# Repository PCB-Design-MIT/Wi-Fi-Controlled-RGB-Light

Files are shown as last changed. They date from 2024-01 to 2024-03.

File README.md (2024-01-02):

# Wi-Fi-Controlled-RGB-Light

A demo board for students to learn to solder and debug

Designed by: [Deepta Gupta](https://github.com/deeptag0307), [Winnie Szeto](https://github.com/wszeto9) for IAP 2024

[Interactive BOM](https://htmlpreview.github.io/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)

[Interactive Schematic and Layout Viewer](https://kicanvas.org/?github=https%3A%2F%2Fgithub.com%2FPCB-Design-MIT%2FWi-Fi-Controlled-RGB-Light)

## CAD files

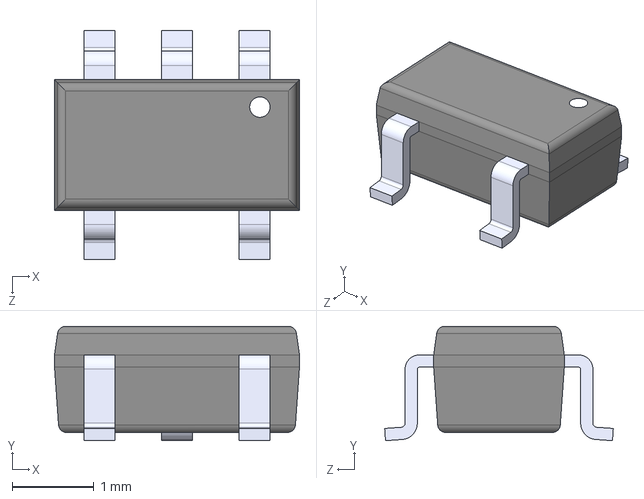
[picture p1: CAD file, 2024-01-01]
parts/AP2112K-3.3TRG1/AP2112K-3.3TRG1.step
3.00 x 1.40 x 2.80 mm

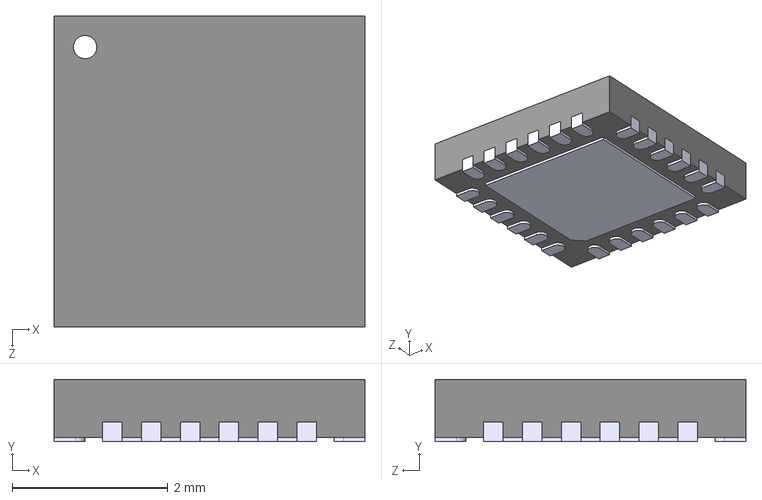
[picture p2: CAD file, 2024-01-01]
parts/CP2104-F03-GM/CP2104-F03-GM.step
4.00 x 0.8 x 4.00 mm

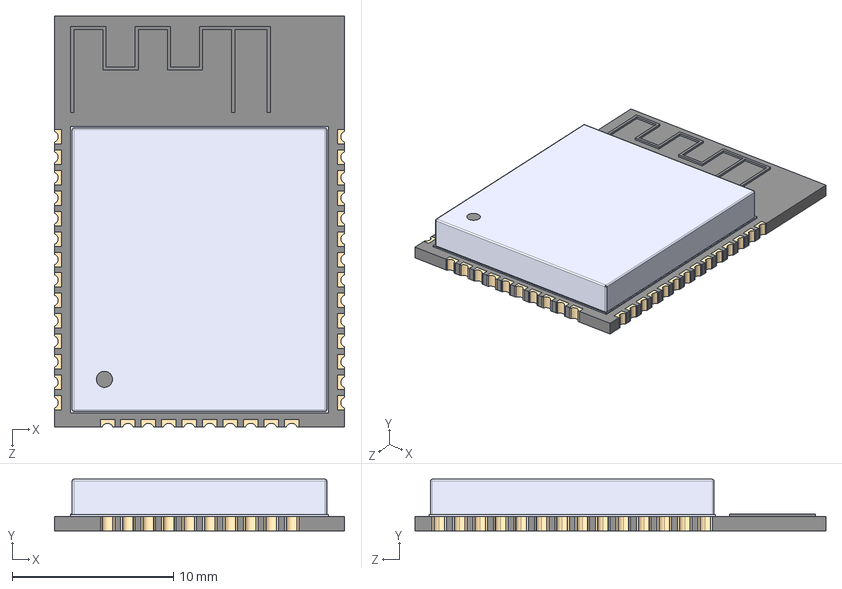
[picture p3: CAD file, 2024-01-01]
parts/ESP32-WROOM-32/ESP32-WROOM-32.step
18.0 x 3.20 x 25.5 mm

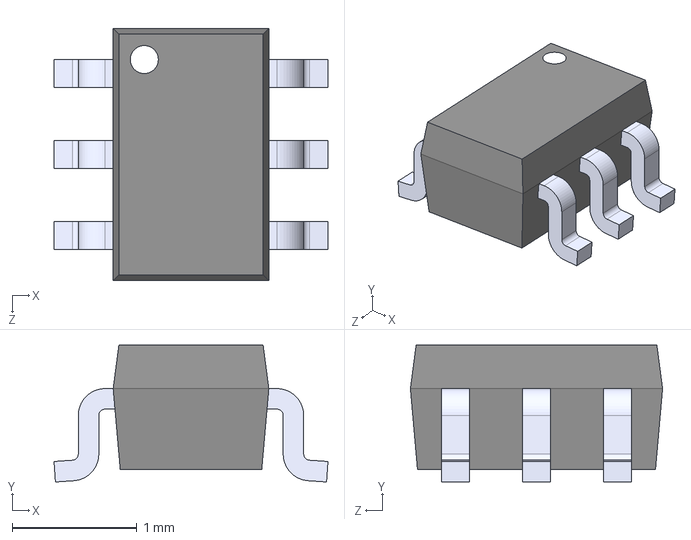
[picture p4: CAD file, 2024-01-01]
parts/MBT3904DW1T1G/MBT3904DW1T1G.step
2.20 x 1.10 x 2.03 mm

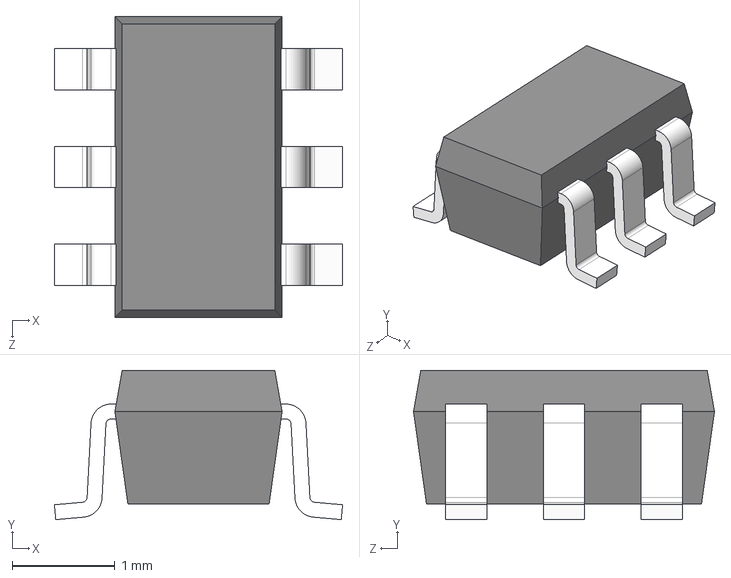
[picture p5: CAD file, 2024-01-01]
parts/TPS61170DRVR/USBLC6-2SC6/USBLC6-2SC6.step
2.80 x 1.45 x 2.92 mm

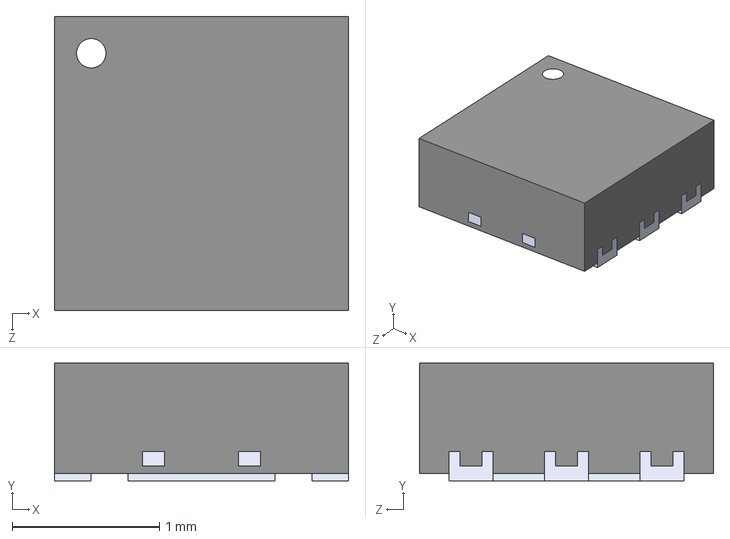
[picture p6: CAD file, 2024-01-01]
parts/TPS61170DRVR/TPS61170DRVR.step
2.00 x 0.8 x 2.00 mm

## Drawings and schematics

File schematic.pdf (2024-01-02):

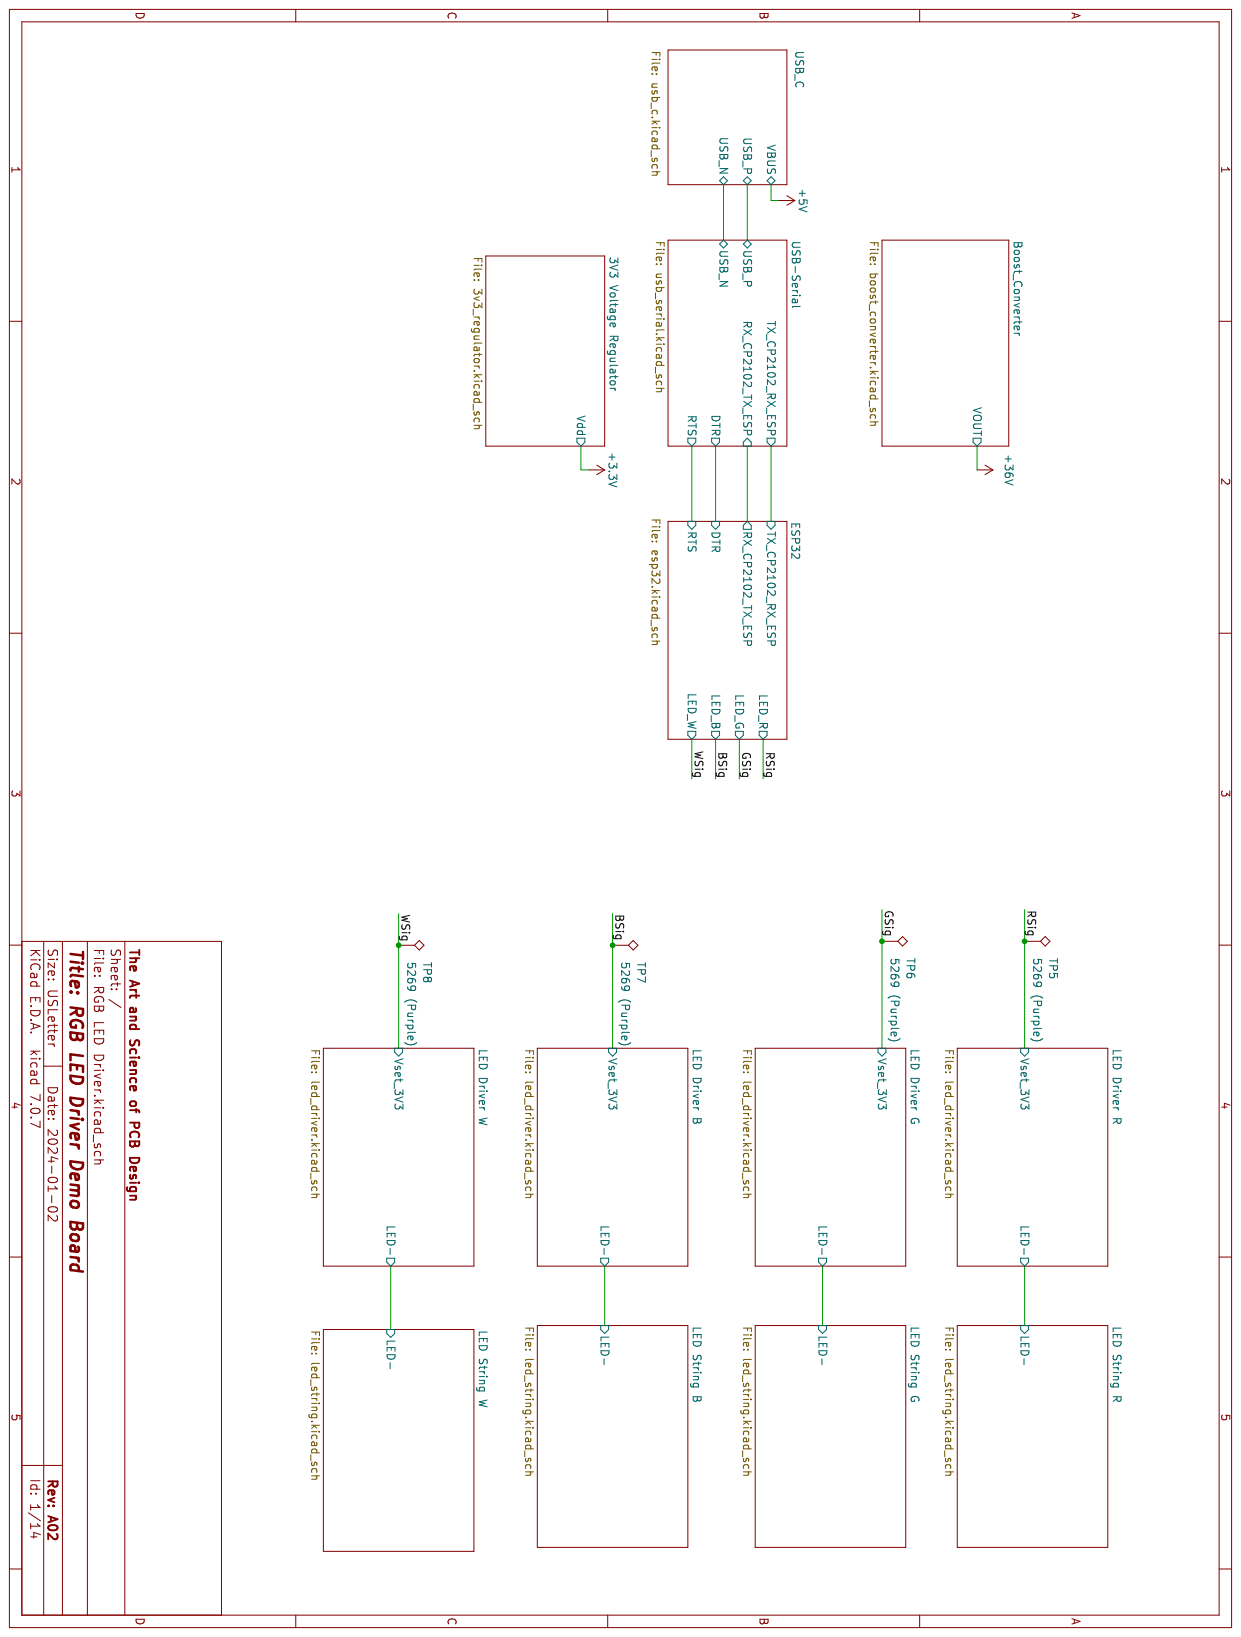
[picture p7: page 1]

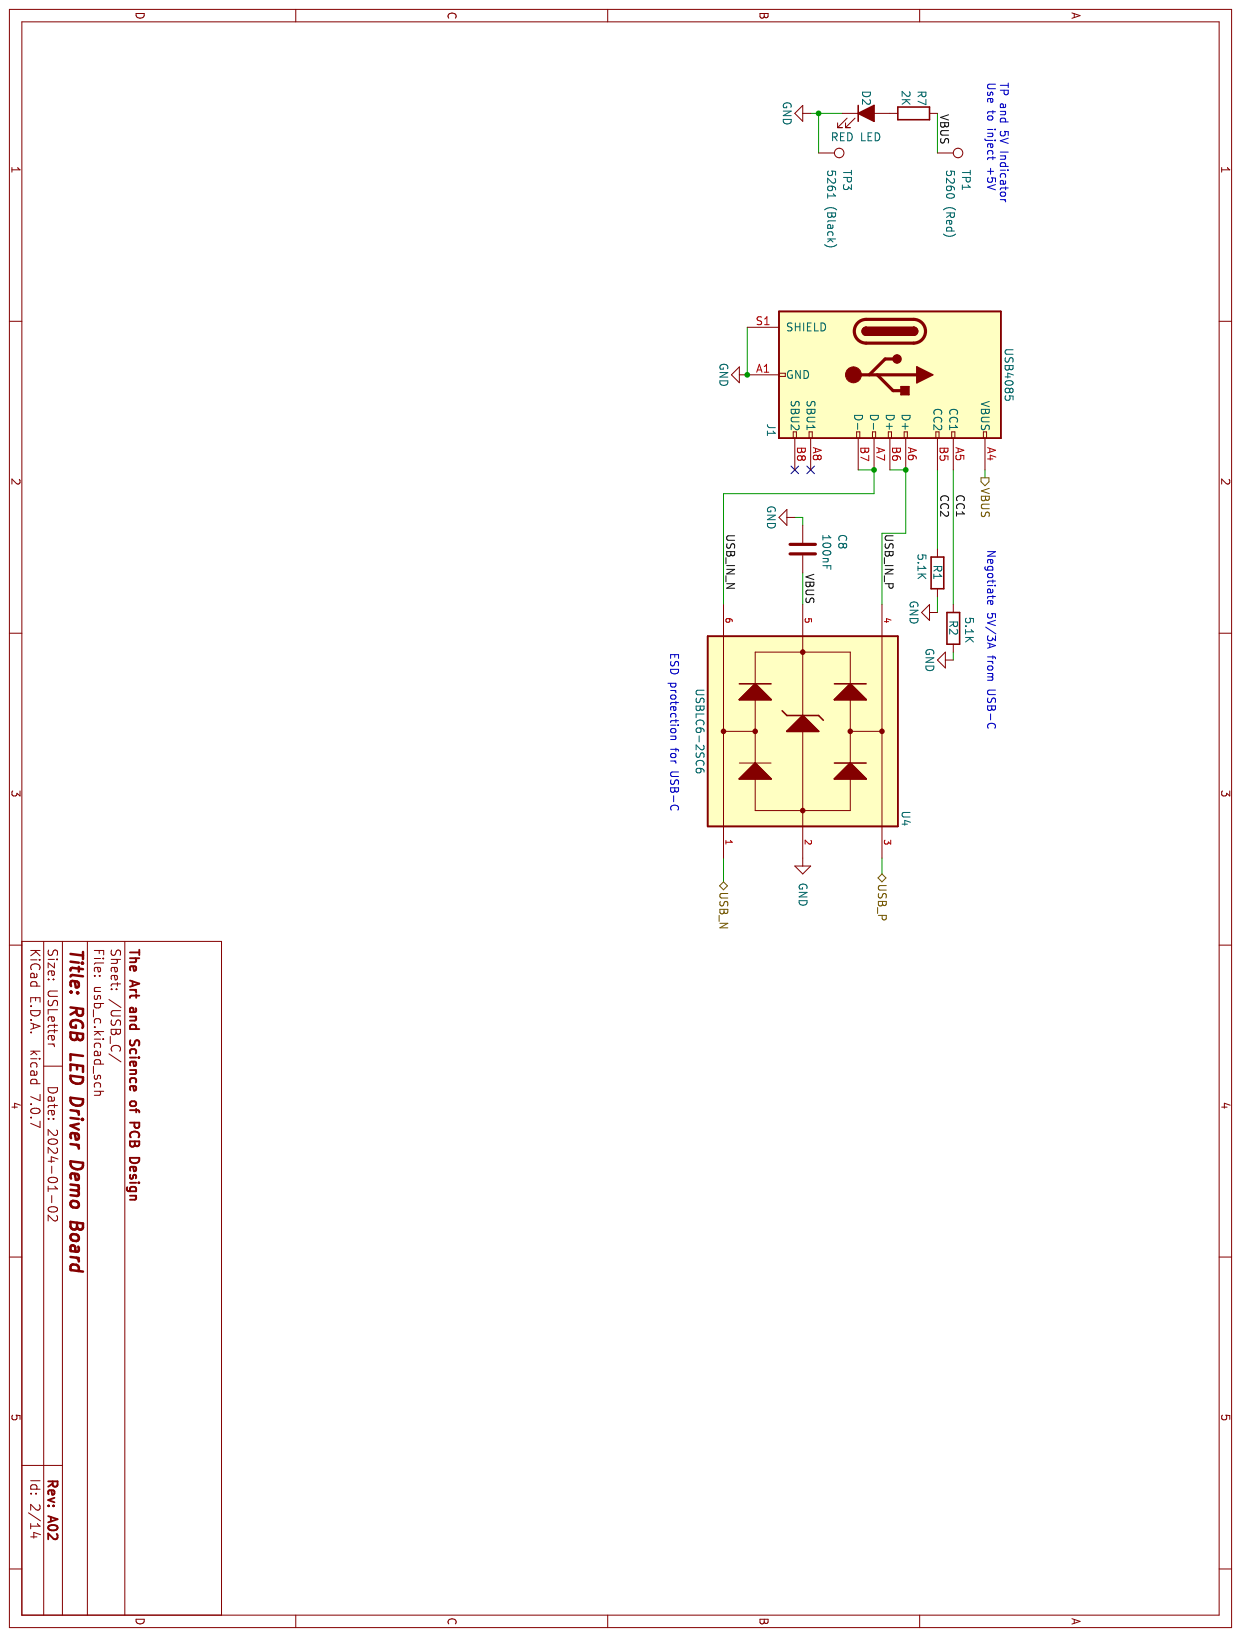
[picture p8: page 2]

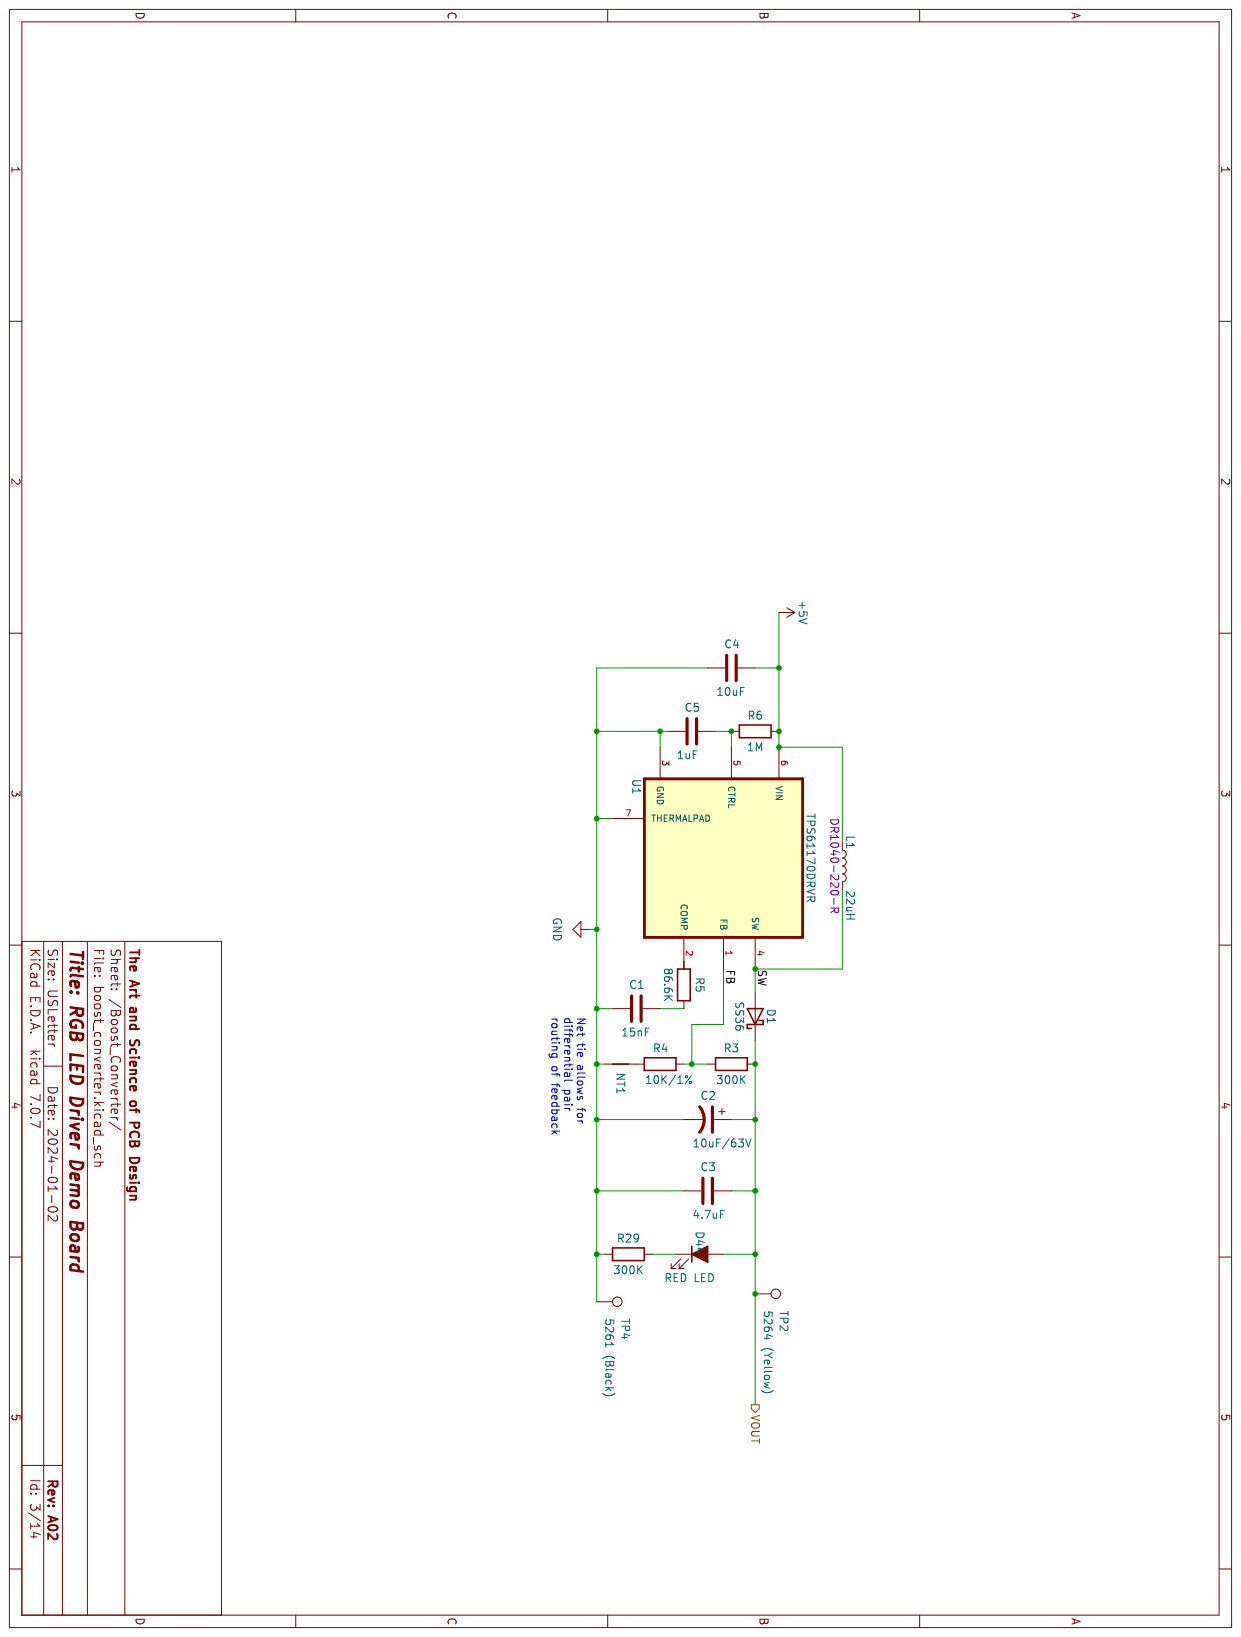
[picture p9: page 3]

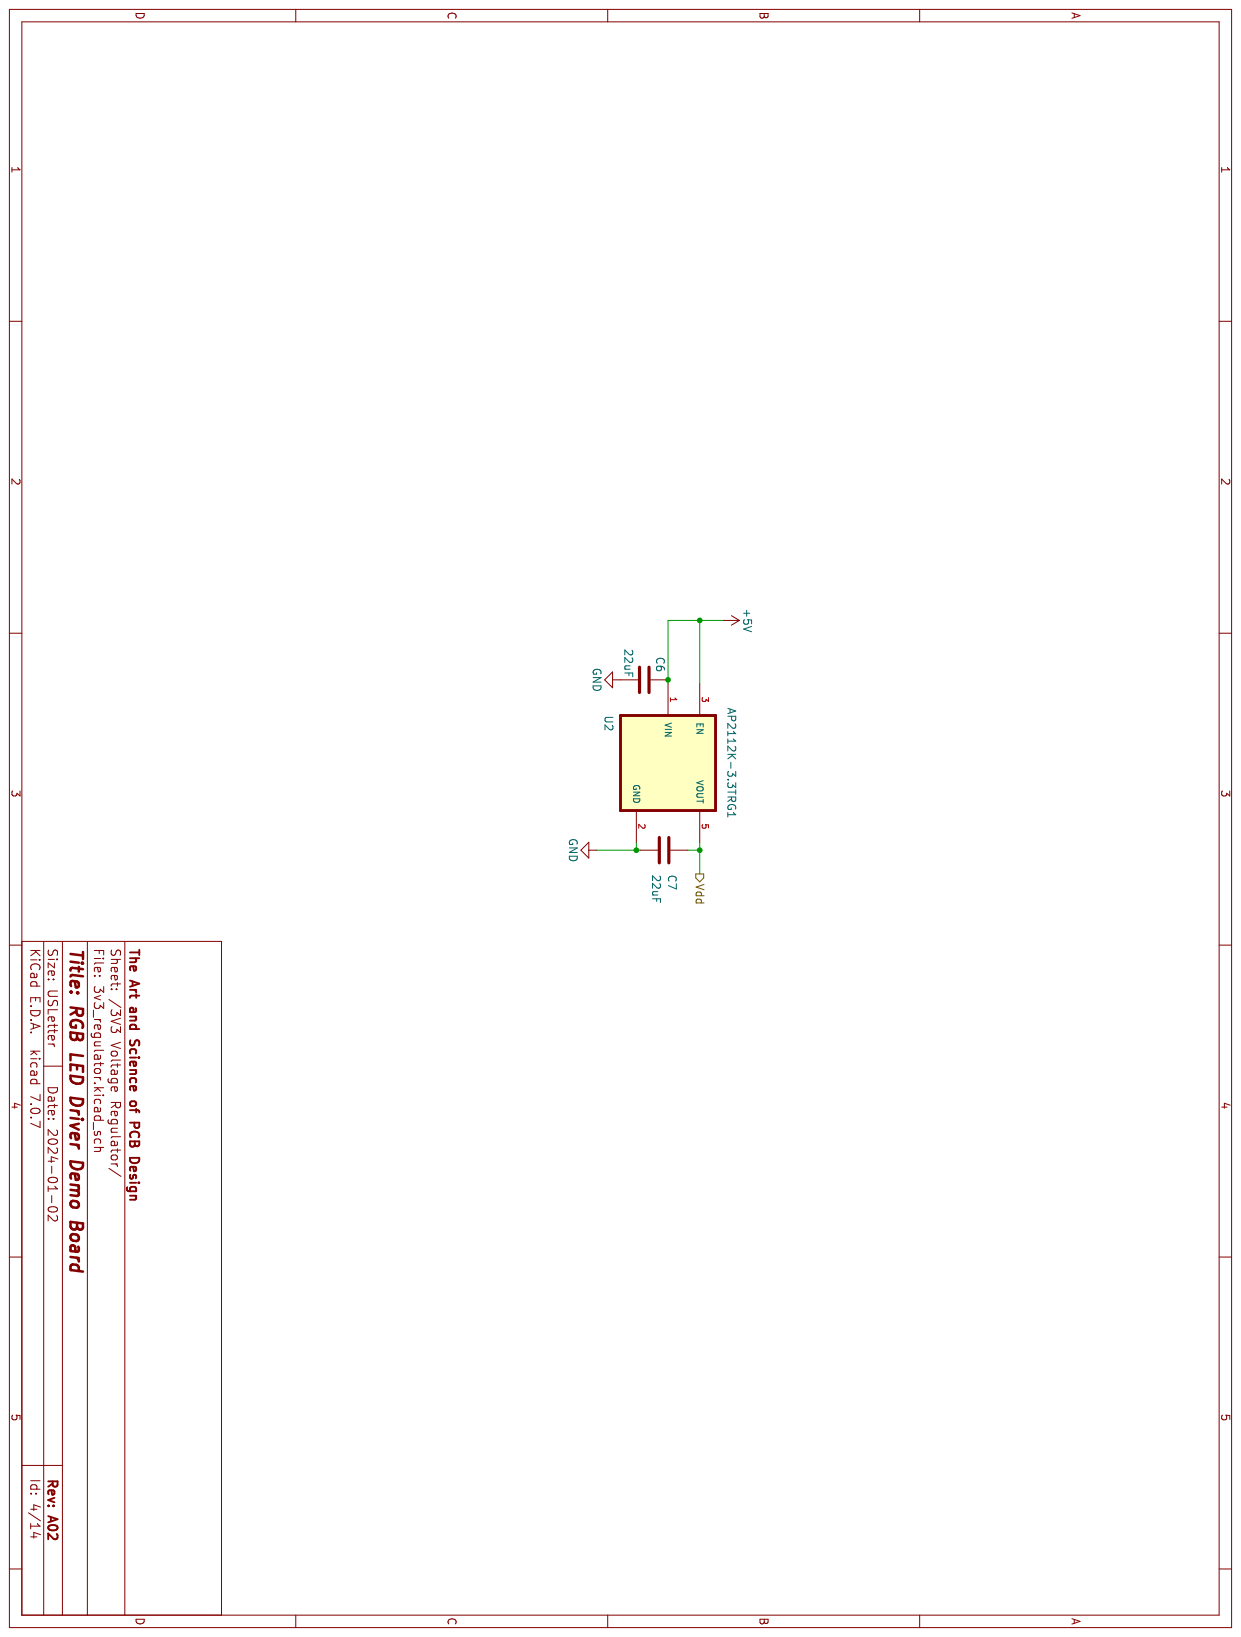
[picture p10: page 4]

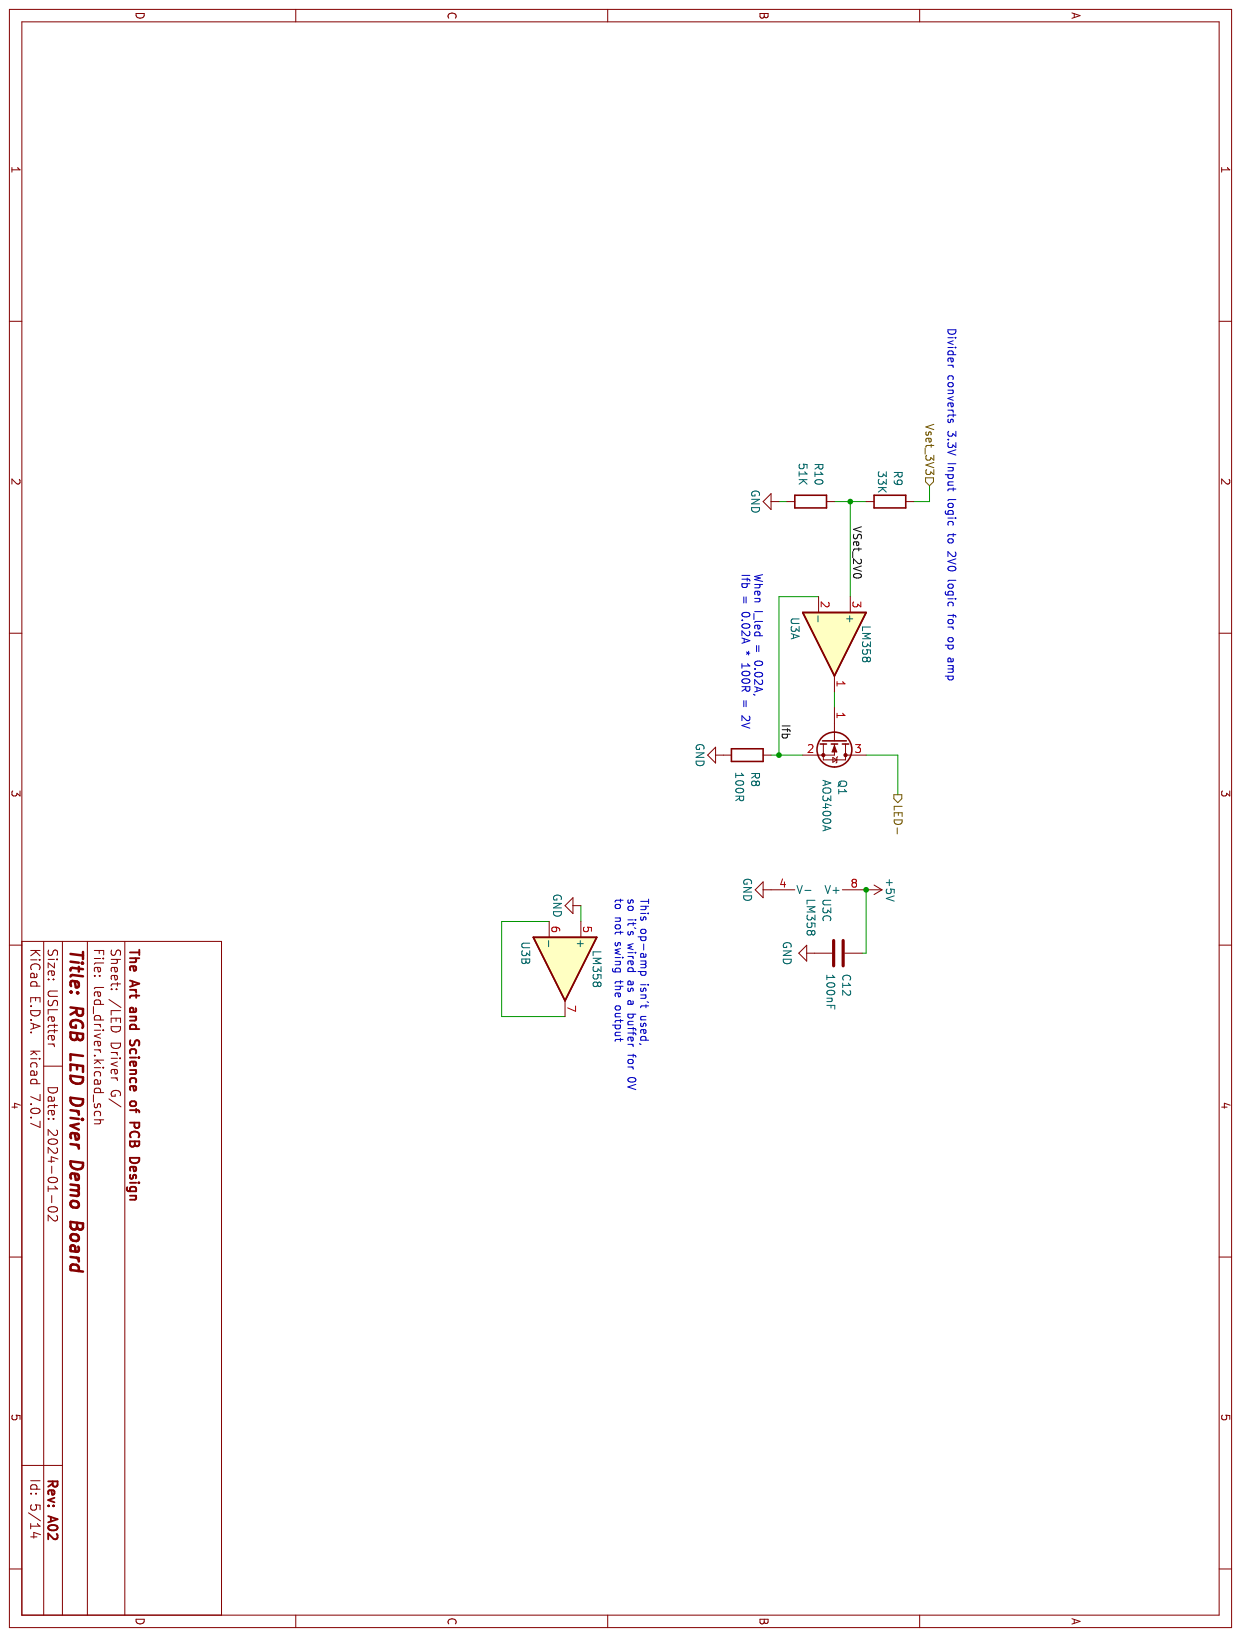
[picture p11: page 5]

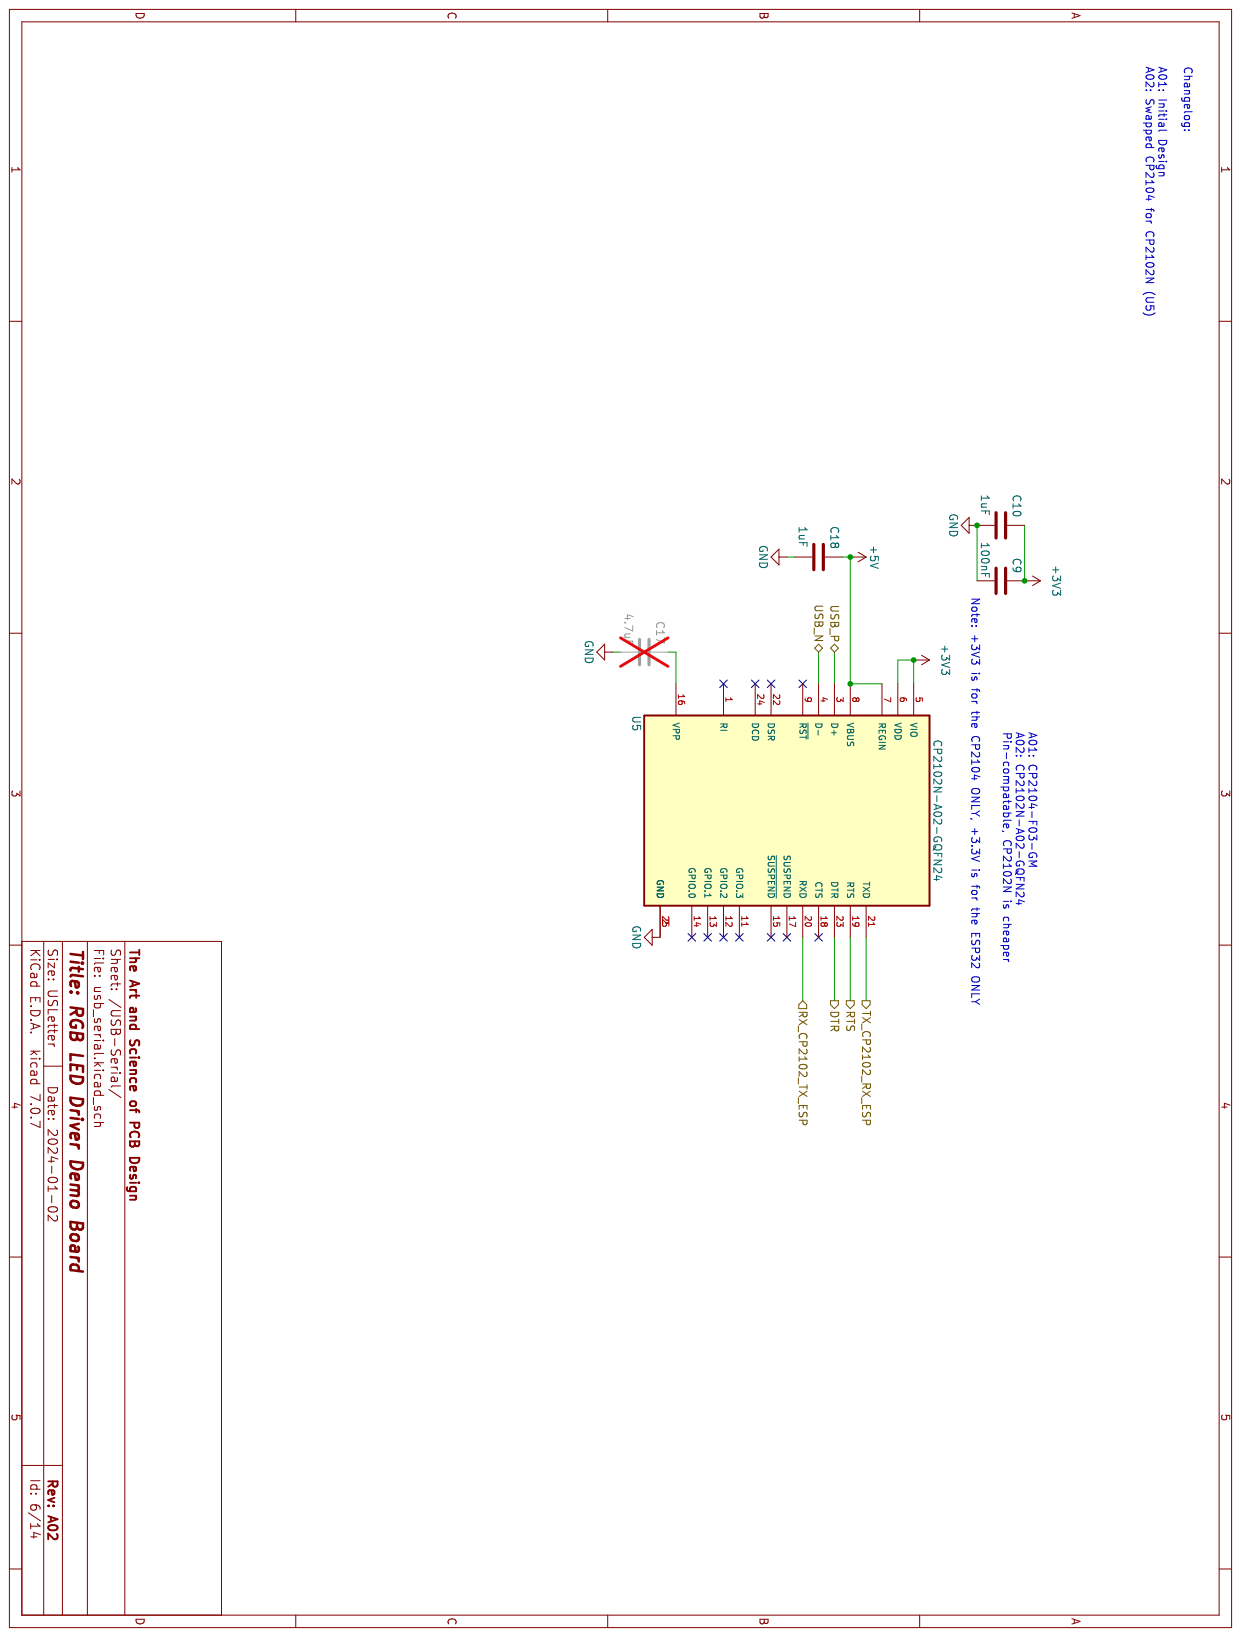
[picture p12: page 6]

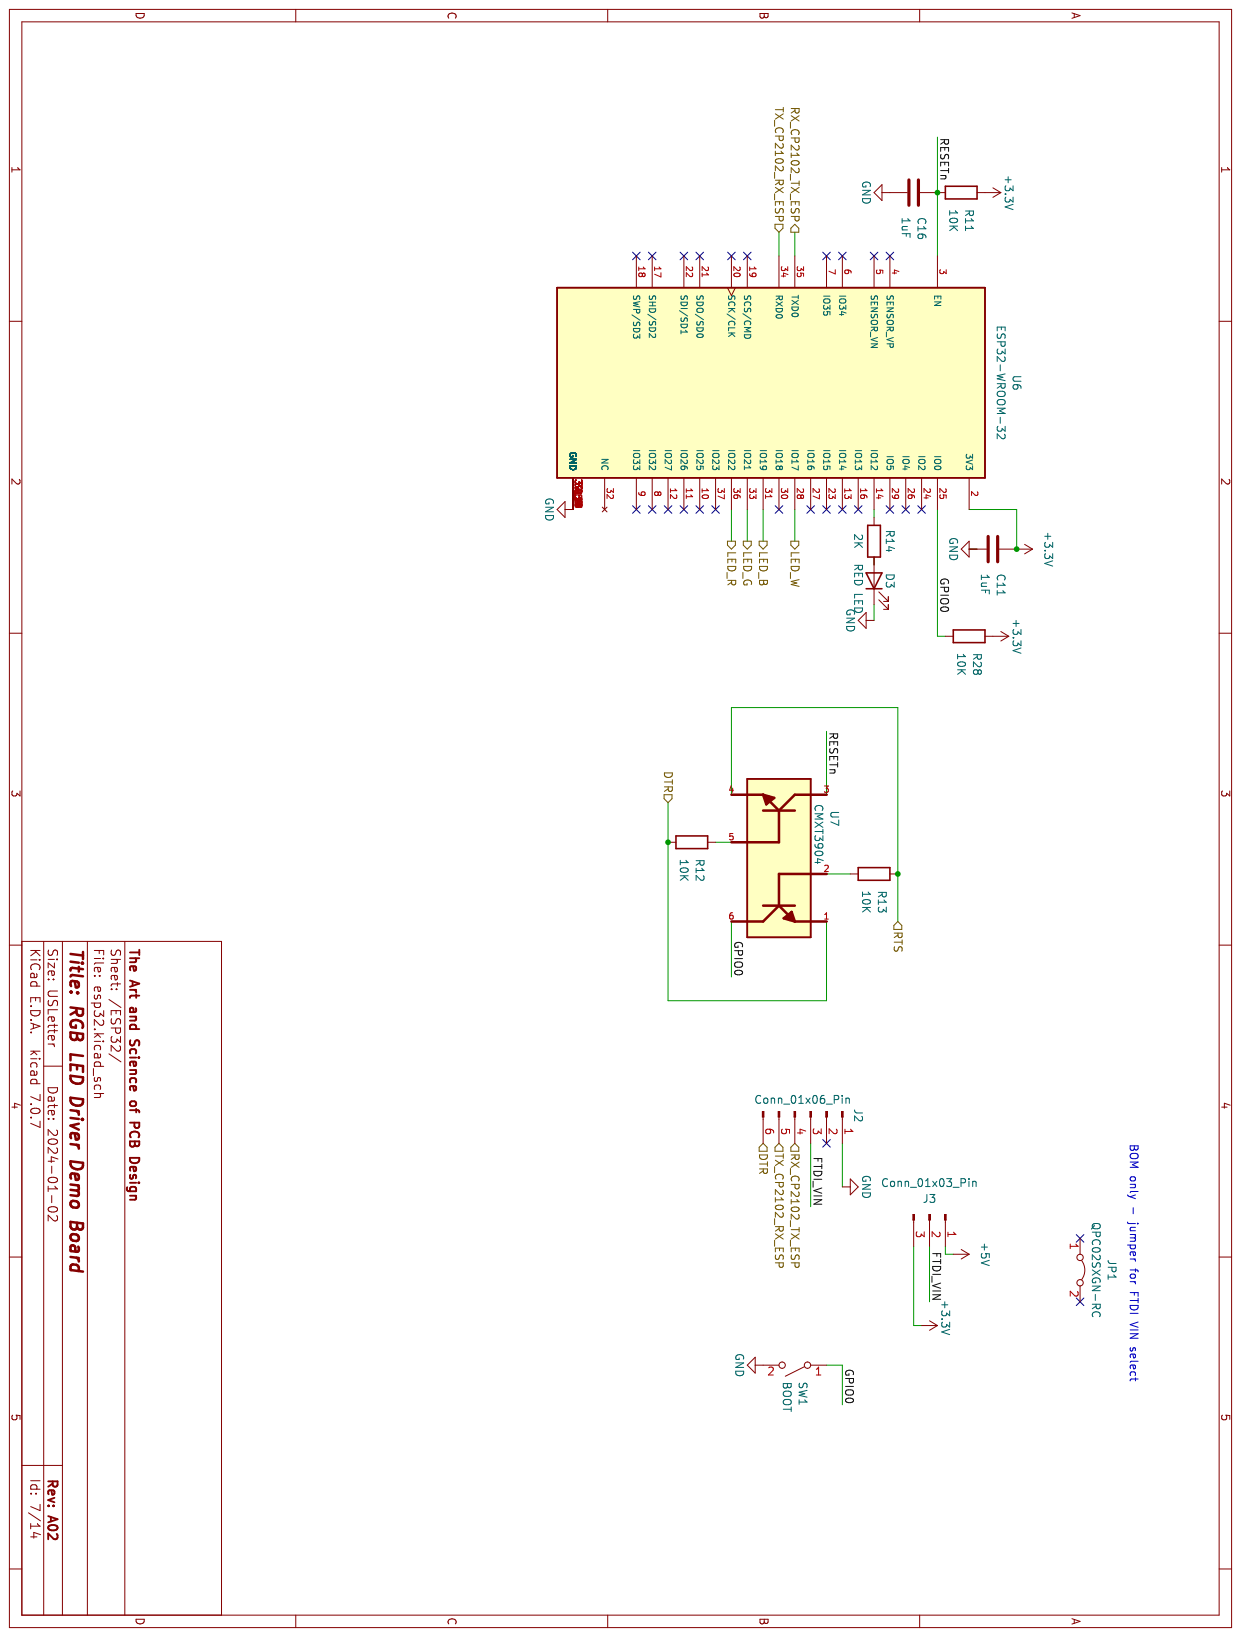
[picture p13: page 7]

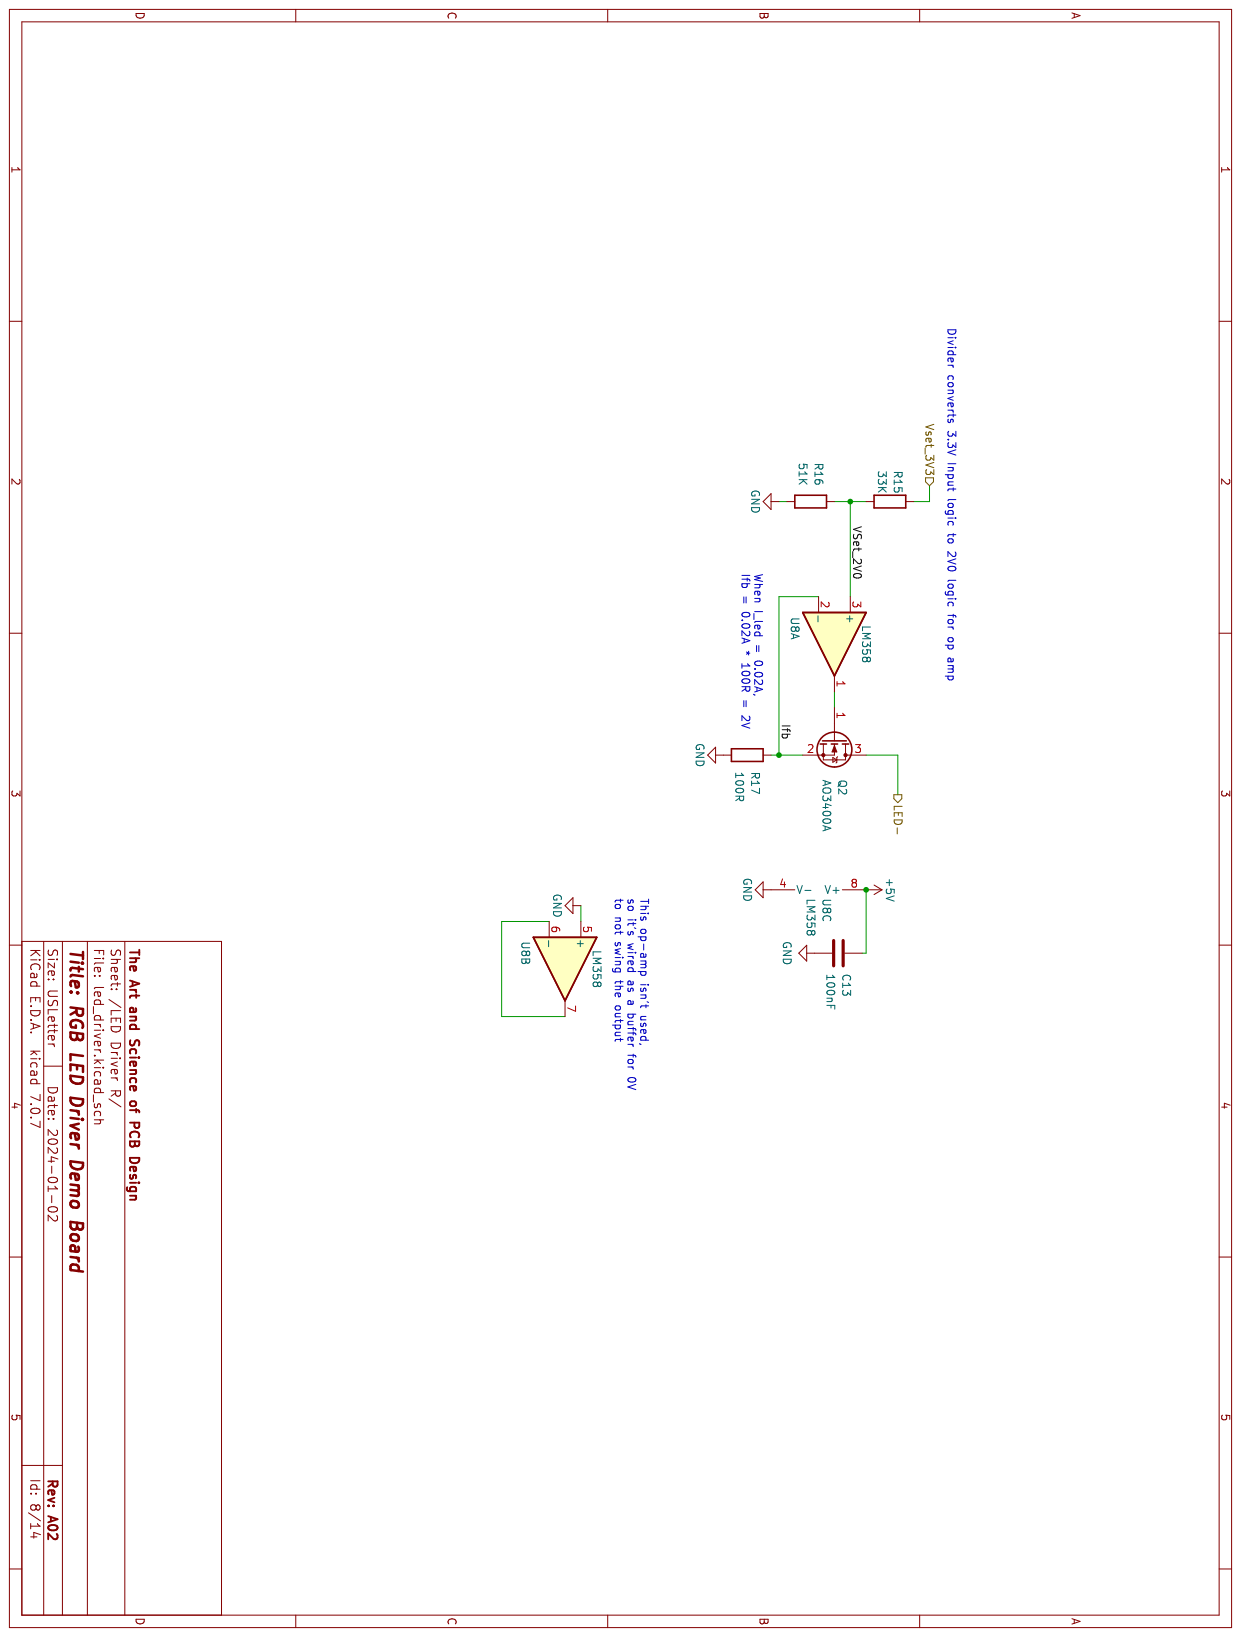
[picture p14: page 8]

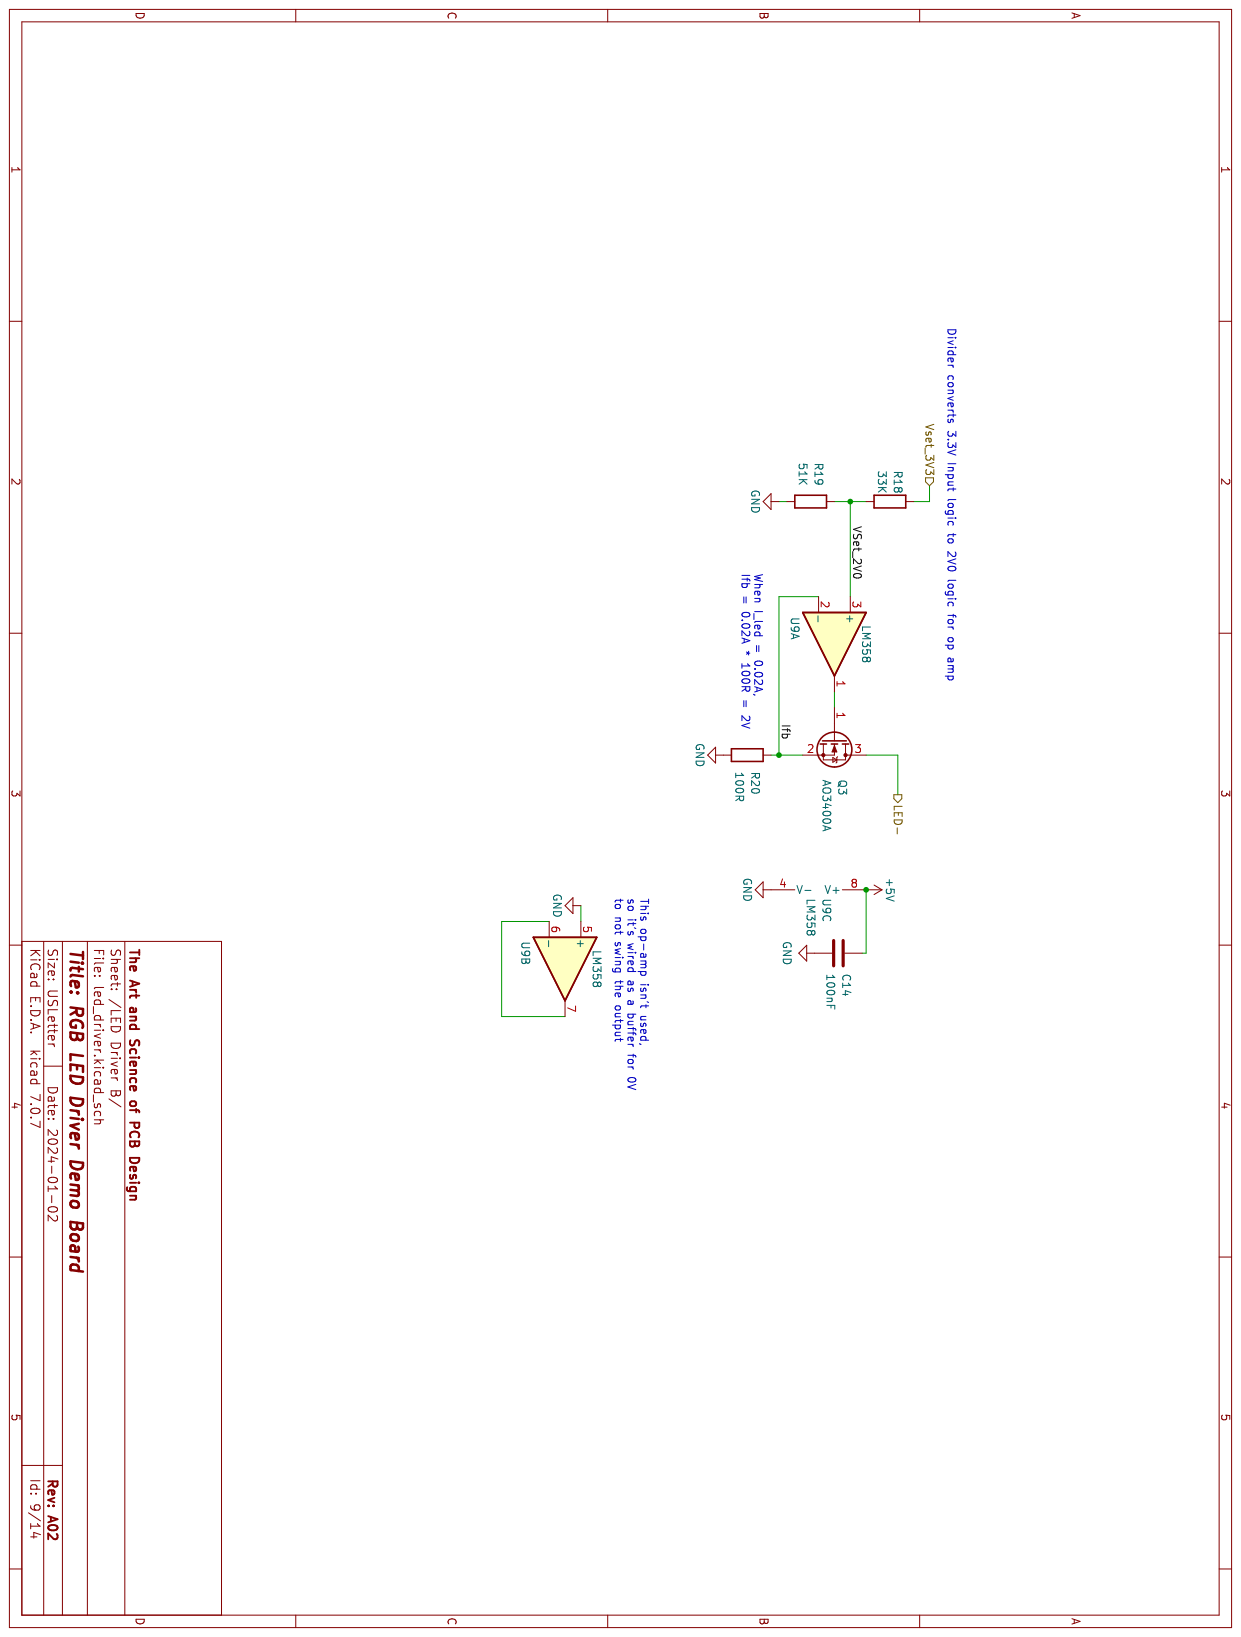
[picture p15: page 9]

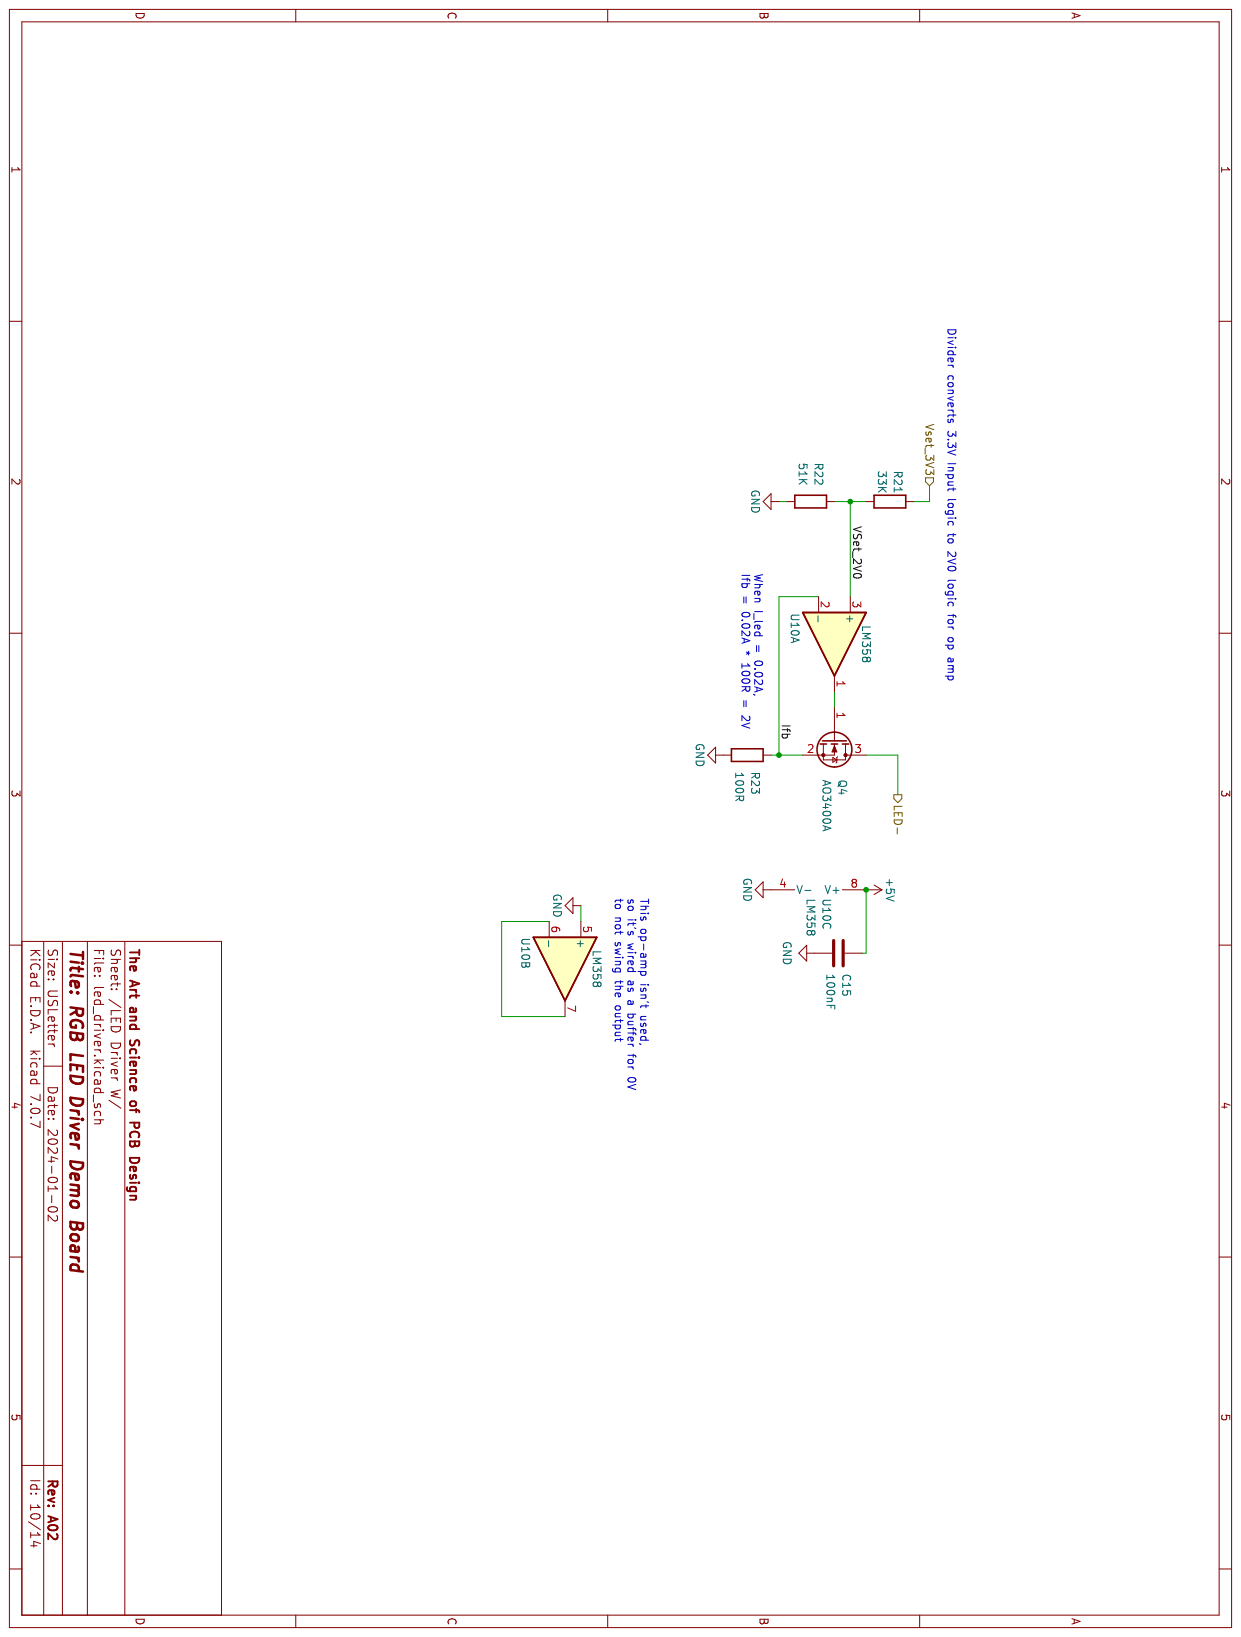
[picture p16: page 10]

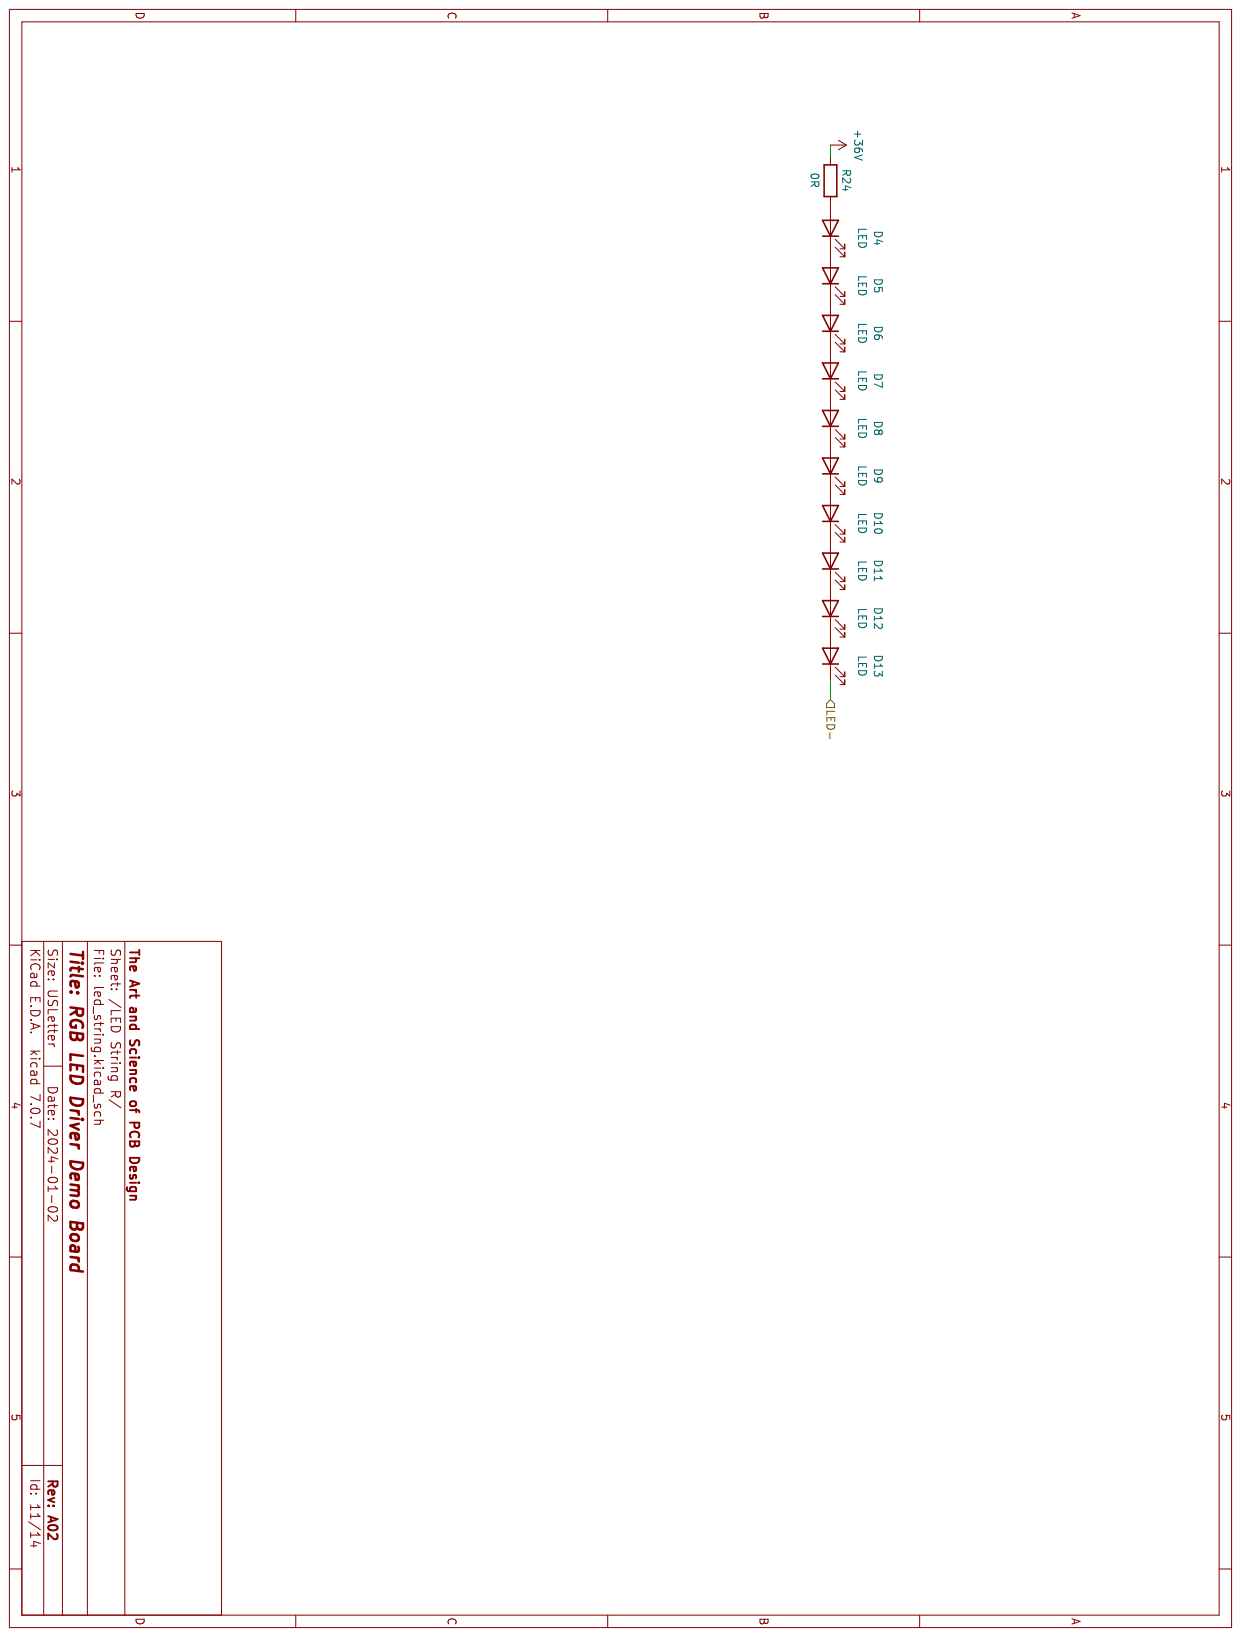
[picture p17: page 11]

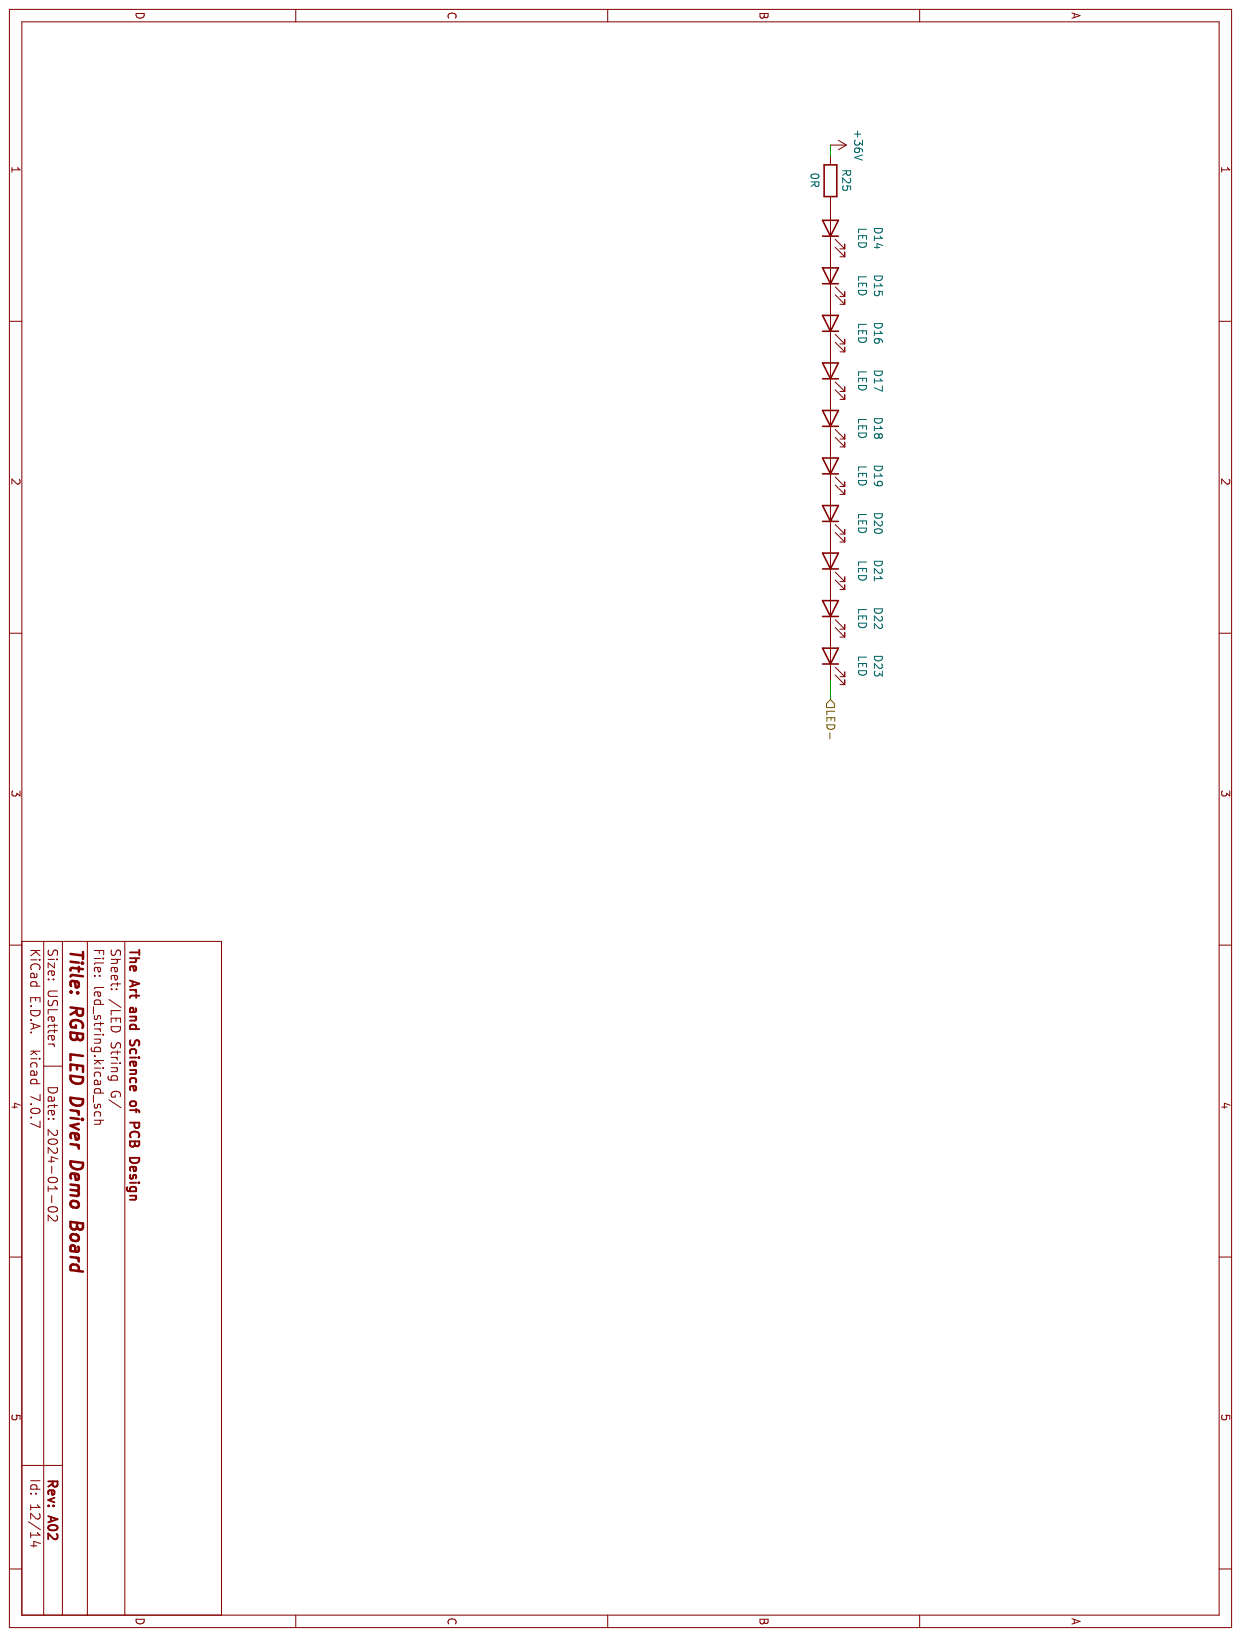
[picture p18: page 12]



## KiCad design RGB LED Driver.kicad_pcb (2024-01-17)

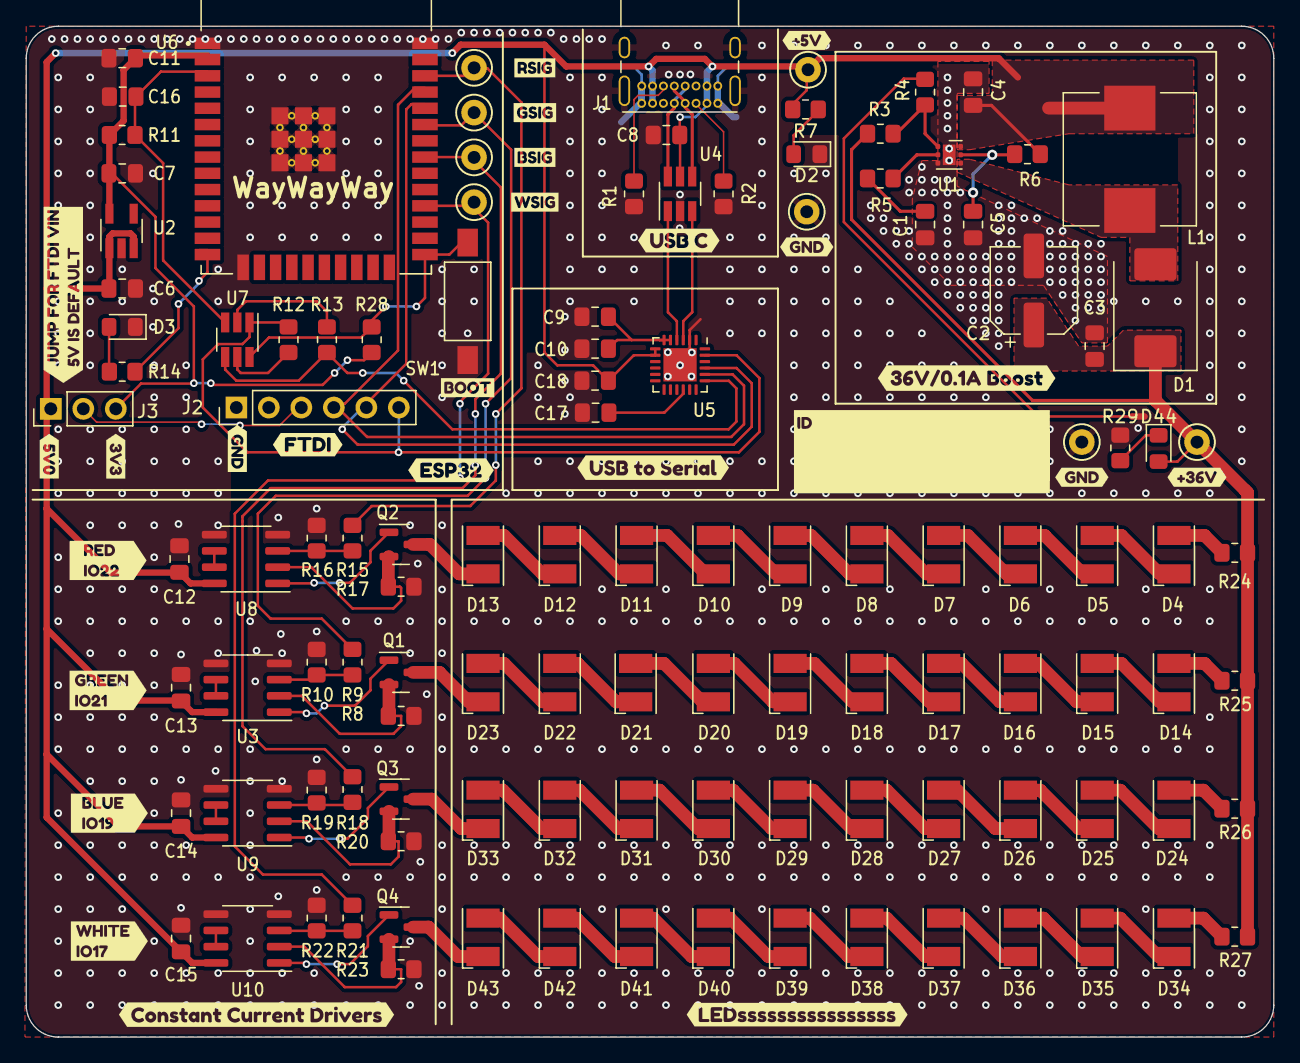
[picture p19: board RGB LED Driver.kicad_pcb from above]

Board: 2 copper layers, 97.5 x 79.0 mm, 144 parts (0 on the bottom side), 95 nets.

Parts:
C1: 15nF; C_0805_2012Metric_Pad1.18x1.45mm_HandSolder
C2: 10uF/63V; CP_Elec_6.3x5.8
C3, C17: 4.7uF; C_0805_2012Metric_Pad1.18x1.45mm_HandSolder
C4: 10uF; C_0805_2012Metric_Pad1.18x1.45mm_HandSolder
C5, C10, C11, C16, C18: 1uF; C_0805_2012Metric_Pad1.18x1.45mm_HandSolder
C6, C7: 22uF; C_0805_2012Metric_Pad1.18x1.45mm_HandSolder
C8, C9, C12, C13, C14, C15: 100nF; C_0805_2012Metric_Pad1.18x1.45mm_HandSolder
D1: SS36; D_SMC
D2, D3, D44: RED LED; LED_0805_2012Metric_Pad1.15x1.40mm_HandSolder
D4, D5, D6, D7, D8, D9, D10, D11, D12, D13, D14, D15, D16, D17, D18, D19, D20, D21, D22, D23, D24, D25, D26, D27, D28, D29, D30, D31, D32, D33, D34, D35, D36, D37, D38, D39, D40, D41, D42, D43: LED; LED_PLCC-2_3.4x3.0mm_KA
J1: USB4085; USB_C_Receptacle_GCT_USB4085
J2: Conn_01x06_Pin; PinHeader_1x06_P2.54mm_Vertical
J3: Conn_01x03_Pin; PinHeader_1x03_P2.54mm_Vertical
L1: 22uH; L_Wuerth_HCI-1040
NT1: Nettie; NetTie-2_SMD_Pad0.5mm
Q1, Q2, Q3, Q4: AO3400A; SOT-23
R1, R2: 5.1K; R_0805_2012Metric_Pad1.20x1.40mm_HandSolder
R3: 270K; R_0805_2012Metric_Pad1.20x1.40mm_HandSolder
R4, R12, R13, R28: 10K; R_0805_2012Metric_Pad1.20x1.40mm_HandSolder
R5: 86.6K; R_0805_2012Metric_Pad1.20x1.40mm_HandSolder
R6: 1M; R_0805_2012Metric_Pad1.20x1.40mm_HandSolder
R7, R14: 2K; R_0805_2012Metric_Pad1.20x1.40mm_HandSolder
R8, R17, R20, R23: 100R; R_0805_2012Metric_Pad1.20x1.40mm_HandSolder
R9, R15, R18, R21: 33K; R_0805_2012Metric_Pad1.20x1.40mm_HandSolder
R10, R11, R16, R19, R22: 51K; R_0805_2012Metric_Pad1.20x1.40mm_HandSolder
R24, R25, R26, R27: 0R; R_0805_2012Metric_Pad1.20x1.40mm_HandSolder
R29: 300K; R_0805_2012Metric_Pad1.20x1.40mm_HandSolder
SW1: BOOT; SW_SPST_FSMSM
TP1: 5260 (Red); TestPoint_Keystone_5000-5004_Miniature
TP2: 5264 (Yellow); TestPoint_Keystone_5000-5004_Miniature
TP3, TP4: 5261 (Black); TestPoint_Keystone_5000-5004_Miniature
TP5, TP6, TP7, TP8: 5269 (Purple); TestPoint_Keystone_5000-5004_Miniature
U1: TPS61170DRVR; WSON-6-1EP_2x2mm_P0.65mm_EP1x1.6mm
U2: AP2112K-3.3TRG1; SOT-23-5_HandSoldering
U3, U8, U9, U10: LM358; SOIC-8_3.9x4.9mm_P1.27mm
U4: USBLC6-2SC6; SOT-23-6_Handsoldering
U5: CP2102N-A02-GQFN24; QFN-24-1EP_4x4mm_P0.5mm_EP2.6x2.6mm
U6: ESP32-WROOM-32; ESP32
U7: CMXT3904; SOT-23-6_Handsoldering
kibuzzard-6592DDED: G***; kibuzzard-6592DDED
kibuzzard-65932B4E: G***; kibuzzard-65932B4E
kibuzzard-65932B20: G***; kibuzzard-65932B20
kibuzzard-65932B45: G***; kibuzzard-65932B45
kibuzzard-65932B54: G***; kibuzzard-65932B54
kibuzzard-65932F0E: G***; kibuzzard-65932F0E
kibuzzard-65932F1A: G***; kibuzzard-65932F1A
kibuzzard-65932F14: G***; kibuzzard-65932F14
kibuzzard-65932F21: G***; kibuzzard-65932F21
kibuzzard-659323CF: G***; kibuzzard-659323CF
kibuzzard-659324E3: G***; kibuzzard-659324E3
kibuzzard-659325DE: G***; kibuzzard-659325DE
kibuzzard-659433EE: G***; kibuzzard-659433EE
kibuzzard-6593238E: G***; kibuzzard-6593238E
kibuzzard-6593379A: G***; kibuzzard-6593379A
kibuzzard-6594327C: G***; kibuzzard-6594327C
kibuzzard-6594332E: G***; kibuzzard-6594332E
kibuzzard-65932266: G***; kibuzzard-65932266
kibuzzard-65932378, kibuzzard-65932378#2: G***; kibuzzard-65932378
kibuzzard-65932434: G***; kibuzzard-65932434
kibuzzard-65932443: G***; kibuzzard-65932443
kibuzzard-65932491: G***; kibuzzard-65932491
kibuzzard-65932806: G***; kibuzzard-65932806
kibuzzard-65943322: G***; kibuzzard-65943322

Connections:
+3.3V: C7.1, C11.1, J3.3, R11.1, R28.1, U2.5 (VOUT), U6.2 (3V3)
+3V3: C9.1, C10.1, U5.5 (VIO), U5.6 (VDD)
+5V: C4.1, C6.1, C8.1, C12.1, C13.1, C14.1, C15.1, C18.1, J1.A4 (VBUS), J1.A9 (VBUS), J1.B4 (VBUS), J1.B9 (VBUS), J3.1, L1.1, R6.2, R7.1, TP1.1, U1.6 (VIN), U2.1 (VIN), U2.3 (EN), U3.8 (V+), U4.5, U5.7 (REGIN), U5.8 (VBUS), U8.8 (V+), U9.8 (V+), U10.8 (V+)
+36V: C2.1, C3.1, D1.1 (K), D44.2 (A), R3.2, R24.1, R25.1, R26.1, R27.1, TP2.1
/BSig: R18.1, TP7.1, U6.31 (IO19)
/Boost_Converter/FB: R3.1, R4.1, U1.1 (FB)
/Boost_Converter/SW: D1.2 (A), L1.2, U1.4 (SW)
/ESP32/DTR: J2.6, R12.2, U5.23 (DTR), U7.1
/ESP32/FTDI_VIN: J2.3, J3.2
/ESP32/GPIO0: R28.2, SW1.1 (A), U6.25 (IO0), U7.6
/ESP32/RESETn: C16.1, R11.2, U6.3 (EN), U7.3
/ESP32/RTS: R13.1, U5.19 (RTS), U7.4
/ESP32/RX_CP2102_TX_ESP: J2.4, U5.20 (RXD), U6.35 (TXD0)
/ESP32/TX_CP2102_RX_ESP: J2.5, U5.21 (TXD), U6.34 (RXD0)
/GSig: R9.1, TP6.1, U6.33 (IO21)
/LED Driver B/Ifb: Q3.2 (S), R20.1, U9.2 (-)
/LED Driver B/LED-: D33.1 (K), Q3.3 (D)
/LED Driver B/VSet_2V0: R18.2, R19.1, U9.3 (+)
/LED Driver G/Ifb: Q1.2 (S), R8.1, U3.2 (-)
/LED Driver G/LED-: D23.1 (K), Q1.3 (D)
/LED Driver G/VSet_2V0: R9.2, R10.1, U3.3 (+)
/LED Driver R/Ifb: Q2.2 (S), R17.1, U8.2 (-)
/LED Driver R/LED-: D13.1 (K), Q2.3 (D)
/LED Driver R/VSet_2V0: R15.2, R16.1, U8.3 (+)
/LED Driver W/Ifb: Q4.2 (S), R23.1, U10.2 (-)
/LED Driver W/LED-: D43.1 (K), Q4.3 (D)
/LED Driver W/VSet_2V0: R21.2, R22.1, U10.3 (+)
/RSig: R15.1, TP5.1, U6.36 (IO22)
/USB-Serial/USB_N: U4.1, U5.4 (D-)
/USB-Serial/USB_P: U4.3, U5.3 (D+)
/USB_C/CC1: J1.A5 (CC1), R2.1
/USB_C/CC2: J1.B5 (CC2), R1.1
/USB_C/USB_IN_N: J1.A7 (D-), J1.B7 (D-), U4.6
/USB_C/USB_IN_P: J1.A6 (D+), J1.B6 (D+), U4.4
/WSig: R21.1, TP8.1, U6.28 (IO17)
GND: C1.2, C2.2, C3.2, C4.2, C5.2, C6.2, C7.2, C8.2, C9.2, C10.2, C11.2, C12.2, C13.2, C14.2, C15.2, C16.2, C17.2, C18.2, D2.1 (K), D3.1 (K), J1.A1 (GND), J1.A12 (GND), J1.B1 (GND), J1.B12 (GND), J1.S1 (SHIELD), J2.1, NT1.1, R1.2, R2.2, R8.2, R10.2, R16.2, R17.2, R19.2, R20.2, R22.2, R23.2, R29.1, SW1.2 (B), TP3.1, TP4.1, U1.3 (GND), U1.7 (THERMALPAD), U2.2 (GND), U3.4 (V-), U3.5 (+), U4.2, U5.2 (GND), U5.25 (GND), U6.1 (GND), U6.15 (GND), U6.38 (GND), U6.39_1 (GND), U6.39_2 (GND), U6.39_3 (GND), U6.39_4 (GND), U6.39_5 (GND), U6.39_6 (GND), U6.39_7 (GND), U6.39_8 (GND), U6.39_9 (GND), U6.39_10 (GND), U6.39_12 (GND), U8.4 (V-), U8.5 (+), U9.4 (V-), U9.5 (+), U10.4 (V-), U10.5 (+)
unnamed: C1.1, R5.2
unnamed: D2.2 (A), R7.2
unnamed: D3.2 (A), R14.2
unnamed: D4.2 (A), R24.2
unnamed: D4.1 (K), D5.2 (A)
unnamed: D5.1 (K), D6.2 (A)
unnamed: D6.1 (K), D7.2 (A)
unnamed: D7.1 (K), D8.2 (A)
unnamed: D8.1 (K), D9.2 (A)
unnamed: D9.1 (K), D10.2 (A)
unnamed: D10.1 (K), D11.2 (A)
unnamed: D11.1 (K), D12.2 (A)
unnamed: D12.1 (K), D13.2 (A)
unnamed: D14.2 (A), R25.2
unnamed: D14.1 (K), D15.2 (A)
unnamed: D15.1 (K), D16.2 (A)
unnamed: D16.1 (K), D17.2 (A)
unnamed: D17.1 (K), D18.2 (A)
unnamed: D18.1 (K), D19.2 (A)
unnamed: D19.1 (K), D20.2 (A)
unnamed: D20.1 (K), D21.2 (A)
unnamed: D21.1 (K), D22.2 (A)
unnamed: D22.1 (K), D23.2 (A)
unnamed: D24.2 (A), R26.2
unnamed: D24.1 (K), D25.2 (A)
unnamed: D25.1 (K), D26.2 (A)
unnamed: D26.1 (K), D27.2 (A)
unnamed: D27.1 (K), D28.2 (A)
unnamed: D28.1 (K), D29.2 (A)
unnamed: D29.1 (K), D30.2 (A)
unnamed: D30.1 (K), D31.2 (A)
unnamed: D31.1 (K), D32.2 (A)
unnamed: D32.1 (K), D33.2 (A)
unnamed: D34.2 (A), R27.2
unnamed: D34.1 (K), D35.2 (A)
unnamed: D35.1 (K), D36.2 (A)
unnamed: D36.1 (K), D37.2 (A)
unnamed: D37.1 (K), D38.2 (A)
unnamed: D38.1 (K), D39.2 (A)
unnamed: D39.1 (K), D40.2 (A)
unnamed: D40.1 (K), D41.2 (A)
unnamed: D41.1 (K), D42.2 (A)
unnamed: D42.1 (K), D43.2 (A)
unnamed: D44.1 (K), R29.2
unnamed: NT1.2, R4.2
unnamed: Q1.1 (G), U3.1
unnamed: Q2.1 (G), U8.1
unnamed: Q3.1 (G), U9.1
unnamed: Q4.1 (G), U10.1
unnamed: R12.1, U7.5
unnamed: R13.2, U7.2
unnamed: R5.1, U1.2 (COMP)
unnamed: C5.1, R6.1, U1.5 (CTRL)
unnamed: U3.6 (-), U3.7
unnamed: C17.1, U5.16 (VPP)
unnamed: R14.1, U6.14 (IO12)
unnamed: U8.6 (-), U8.7
unnamed: U9.6 (-), U9.7
unnamed: U10.6 (-), U10.7

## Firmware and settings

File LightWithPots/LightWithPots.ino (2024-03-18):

#define RED 22
#define GREEN 21
#define BLUE 19
#define WHITE 17
#define BRIGHTNESS 34
#define SATURATION 39
#define COLOR 36
void setup() {
  Serial.begin(115200);
  pinMode(RED, OUTPUT);
  pinMode(GREEN, OUTPUT);
  pinMode(BLUE, OUTPUT);
  pinMode(WHITE, OUTPUT);

}

void loop() {
    float brightness_value = (float) analogRead(BRIGHTNESS) / 4095;
    brightness_value = 1 - brightness_value;
    float saturation_value = (float) analogRead(SATURATION) / 4095;
    saturation_value = 1 - saturation_value;
    float color_value = (float) (4095 - analogRead(COLOR)) / 652;

    uint8_t r = uint8_t(127.5 * (cos(color_value) + 1));
    uint8_t g = uint8_t(127.5 * (sin(color_value) + 1));
    uint8_t b = uint8_t(255 - (r + g) / 2);

    analogWrite(RED, (float) saturation_value * brightness_value * r * 0.5);
    analogWrite(GREEN, (float) saturation_value * brightness_value * g);
    analogWrite(BLUE, (float) saturation_value * brightness_value * b * 0.5);
    analogWrite(WHITE, (float) 255 * brightness_value * (1 - saturation_value));
    delay(10);
    Serial.print("BRIGHTNESS: ");
    Serial.print(brightness_value);
    Serial.print(", SATURATION: ");
    Serial.print(saturation_value);
    Serial.print(", COLOR: ");
    Serial.println(color_value);
}

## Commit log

2024-01-01 backing up shit
    [3v3_regulator.kicad_sch, AMS1117-3.3.step, AO3400A.step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]
2024-01-01 laid out stuff
    [3v3_regulator.kicad_sch, RGB LED Driver.kicad_pcb, RGB LED Driver.kicad_sch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]
2024-01-01 added silk for PCBWay to remove customer order
    [RGB LED Driver.kicad_pcb]
2024-01-01 neat-ified schematics
    [3v3_regulator.kicad_sch, RGB LED Driver.kicad_pcb, RGB LED Driver.kicad_sch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]
2024-01-02 Added annotations, BOM count reduction
    LED indicator resistors edited to save on BOM count
    schematics made more neat, added some labels
    [3v3_regulator.kicad_sch, boost_converter.kicad_sch, esp32.kicad_sch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]
2024-01-02 added digikey PNs
    [3v3_regulator.kicad_sch, RGB LED Driver.kicad_sch, boost_converter.kicad_sch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]
2024-01-02 added digikey PNs to all devices
    [boost_converter.kicad_sch, esp32.kicad_sch, led_driver.kicad_sch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]
2024-01-02 updated pcb with BOM
    [RGB LED Driver.kicad_pcb]
2024-01-02 added jumper to FTDI power
    [RGB LED Driver.kicad_pcb, esp32.kicad_sch]
2024-01-02 [A02] Initial release
    CP2014 -> CP2012N (BOM cost reduction)
    [3v3_regulator.kicad_sch, RGB LED Driver.kicad_sch, boost_converter.kicad_sch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]
2024-01-02 deleted unused files
    [AMS1117-3.3.step, AO3400A.step, EEHZA1J100P.step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]
2024-01-02 added interactive schematic
2024-01-02 Added jumper into BOM
    [esp32.kicad_sch]
2024-01-02 cost reduction in BOM
    [boost_converter.kicad_sch, esp32.kicad_sch, usb_serial.kicad_sch]
2024-01-17 [A02] Edited resistor values
    R11 to 51K to allow for auto reset
    R3 to 270K for 34V output
    [RGB LED Driver.kicad_pcb, boost_converter.kicad_sch, esp32.kicad_sch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]
2024-02-14 Create RGB LED Driver.step
